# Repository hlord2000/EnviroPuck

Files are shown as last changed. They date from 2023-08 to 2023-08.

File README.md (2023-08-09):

# EnviroPuck 🌍
Introducing the EnviroPuck, a sleek and low-power environment sensing device, utilizing Raytac's MDBT50Q module featuring the nRF52840 chip, and Bosch's BME688 environmental sensor.

<p align="center">
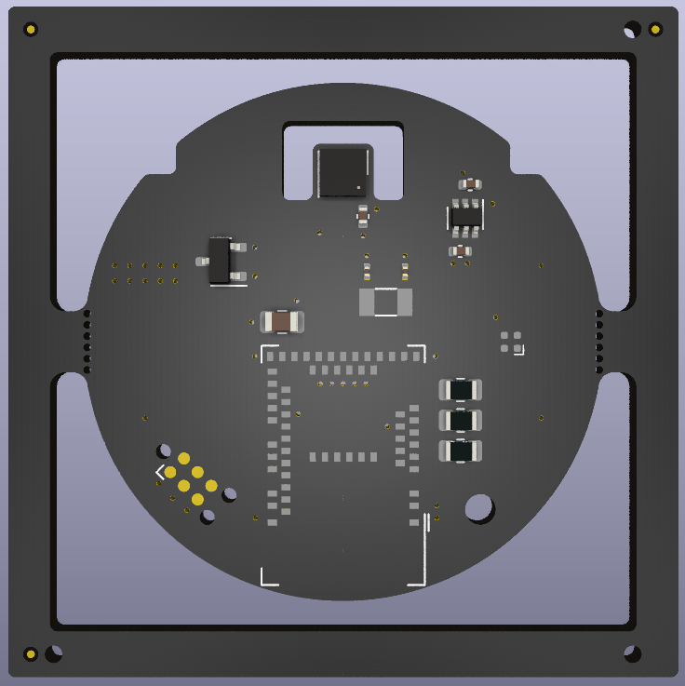
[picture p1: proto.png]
EnviroPuck Prototype
  
</p>

# Features 🎛️
- Raytac MDBT50Q Module with nRF52840: Enables robust wireless connectivity, supporting Matter/Thread protocols 📡
- BME688 Sensor: Accurately monitors temperature, humidity, pressure, and gas conditions 🌡️💧🌀
- Low Power Design: Powered by a single primary cell CR2032, engineered for energy efficiency and long-lasting performance 🔋

# Applications 🏠
- The EnviroPuck is ideal for home automation, indoor climate monitoring, and various IoT applications requiring environmental data.

# Development Status ⚙️
- Hardware: Prototyped
- Firmware: TODO 
- Mechanical Design: TODO

# License 📄
- This project is released under the CERN Open Hardware License V2 - Permissive. More details can be found in the LICENSE file included in the project.

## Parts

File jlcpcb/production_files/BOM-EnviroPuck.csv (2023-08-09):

Comment | Designator | Footprint | LCSC
SC32S-7PF20PPM | Y1 | Crystal_SMD_3215-2Pin_3.2x1.5mm
1k | R5 | R_0805_2012Metric
1k | R4 | R_0805_2012Metric
1k | R3 | R_0805_2012Metric
DMP610DL-7 | Q1 | SOT-23
1u | C6 | C_0402_1005Metric
3.9p | C5 | C_0201_0603Metric
10u | C4 | C_0805_2012Metric
3.9p | C3 | C_0201_0603Metric
100n | C2 | C_0402_1005Metric
1u | C1 | C_0402_1005Metric
LED_RGBA | D1 | LED_Lumex_SML-LX0404SIUPGUSB
MDBT50Q-1MV2 | U3 | Raytac_MDBT50Q
SiP32431DR3 | U1 | SOT-363_SC-70-6
BME680 | U2 | Bosch_LGA-8_3x3mm_P0.8mm_ClockwisePinNumbering
Battery_Cell | BT1 | BatteryHolder_Multicomp_BC-2001_1x2032

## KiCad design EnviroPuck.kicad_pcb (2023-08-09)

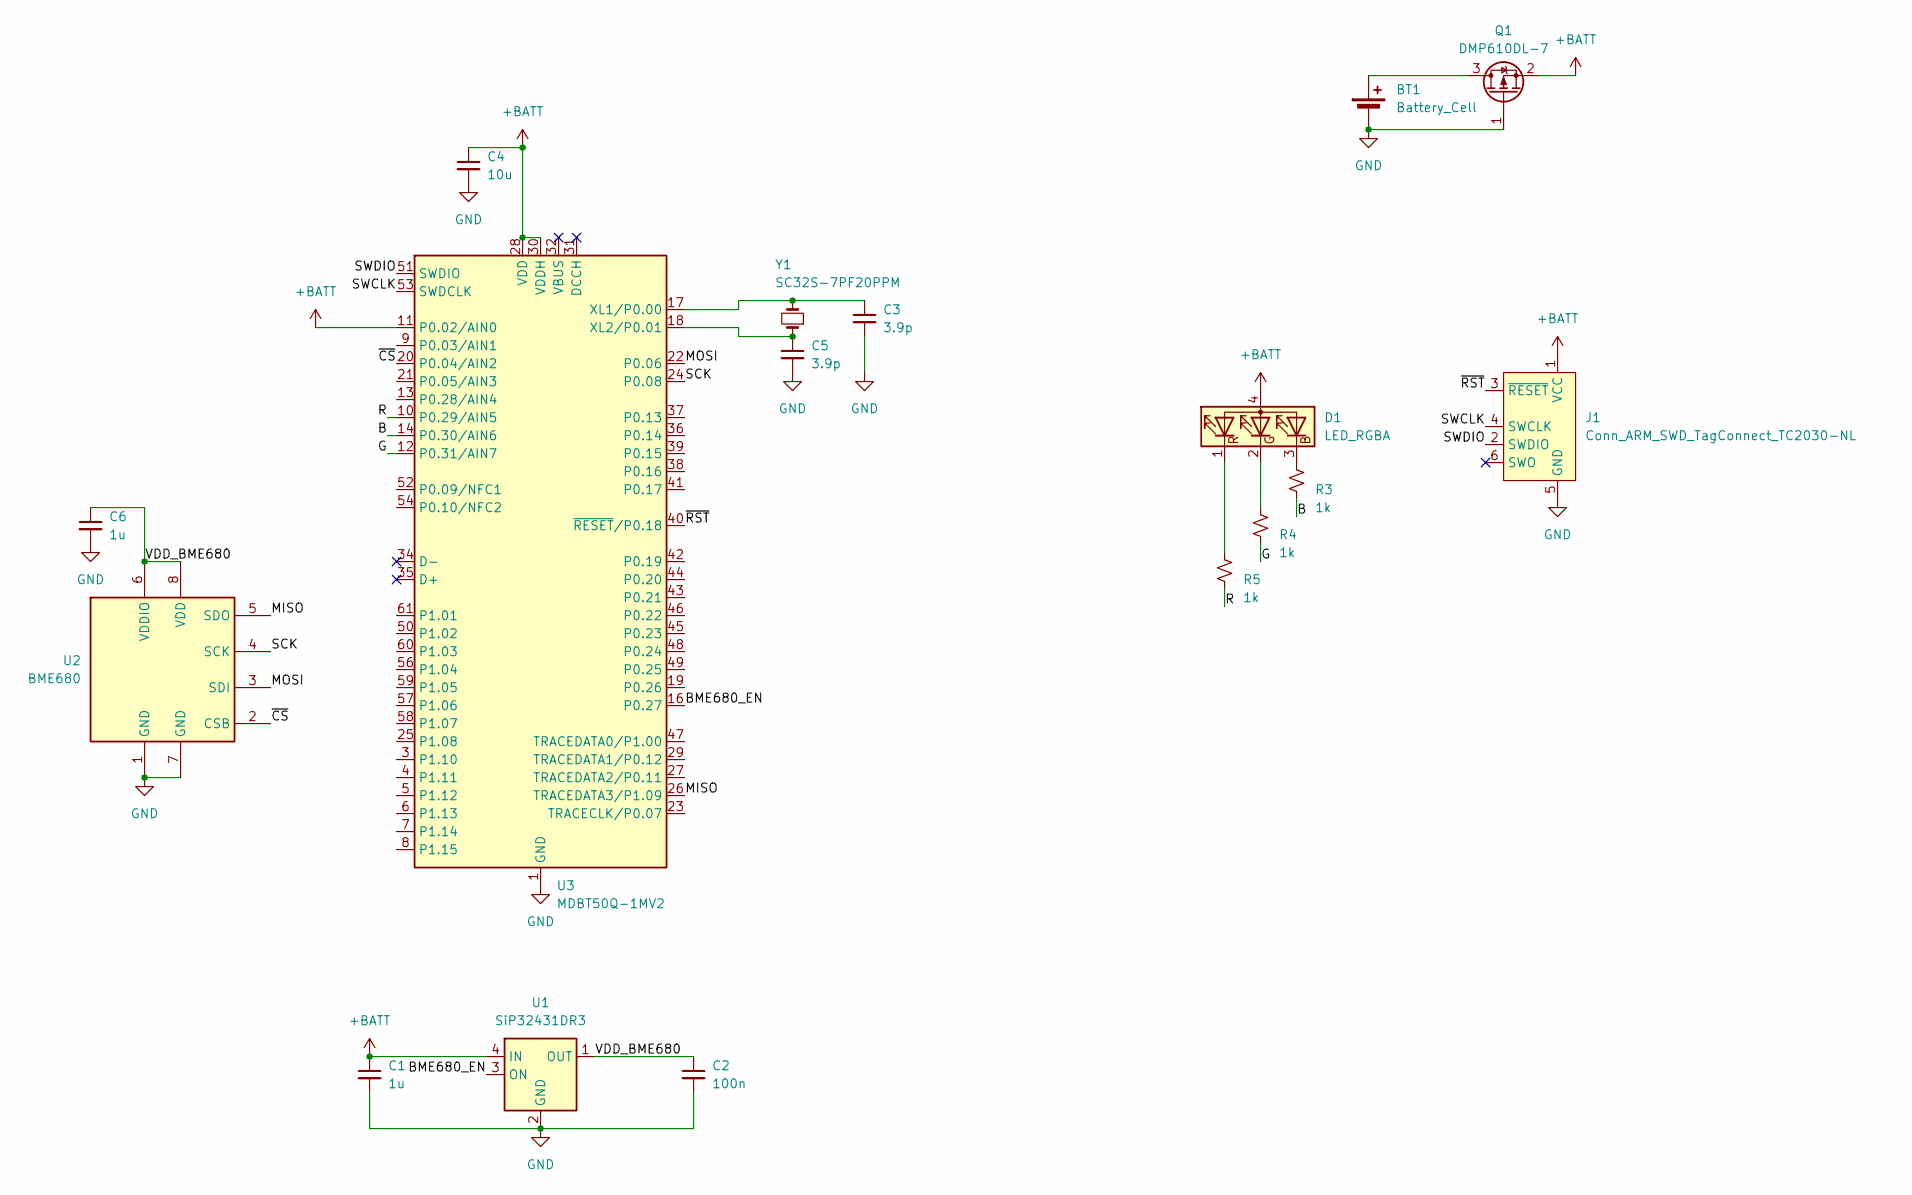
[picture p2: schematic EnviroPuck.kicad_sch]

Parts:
BT1: Battery_Cell; BatteryHolder_Multicomp_BC-2001_1x2032
C1, C6: 1u; C_0402_1005Metric; MPN GRM153C80G105ME15D
C2: 100n; C_0402_1005Metric; MPN CL05B104KA5NNNC
C3, C5: 3.9p; C_0201_0603Metric; MPN GRT0335C1H3R9CA02D
C4: 10u; C_0805_2012Metric; MPN CL21A106KOQNNNE
D1: LED_RGBA; LED_Lumex_SML-LX0404SIUPGUSB
J1: Conn_ARM_SWD_TagConnect_TC2030-NL; Tag-Connect_TC2030-IDC-NL_2x03_P1.27mm_Vertical
Q1: DMP610DL-7; SOT-23; MPN DMP610DL-7
R3, R4, R5: 1k; R_0805_2012Metric; MPN ERJ-6GEYJ102V
U1: SiP32431DR3; SOT-363_SC-70-6
U2: BME680; Bosch_LGA-8_3x3mm_P0.8mm_ClockwisePinNumbering
U3: MDBT50Q-1MV2; Raytac_MDBT50Q
Y1: SC32S-7PF20PPM; Crystal_SMD_3215-2Pin_3.2x1.5mm; MPN SC32S-7PF20PPM

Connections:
+BATT: C1.1, C4.1, D1.4 (A), J1.1 (VCC), Q1.2 (S), U1.4 (IN), U3.11 (P0.02/AIN0), U3.28 (VDD), U3.30 (VDDH)
/B: R3.2, U3.14 (P0.30/AIN6)
/BME680_EN: U1.3 (ON), U3.16 (P0.27)
/G: R4.2, U3.12 (P0.31/AIN7)
/MISO: U2.5 (SDO), U3.26 (TRACEDATA3/P1.09)
/MOSI: U2.3 (SDI), U3.22 (P0.06)
/R: R5.2, U3.10 (P0.29/AIN5)
/SCK: U2.4 (SCK), U3.24 (P0.08)
/SWCLK: J1.4 (SWCLK), U3.53 (SWDCLK)
/SWDIO: J1.2 (SWDIO), U3.51 (SWDIO)
/VDD_BME680: C2.1, C6.1, U1.1 (OUT), U2.6 (VDDIO), U2.8 (VDD)
/~CS: U2.2 (CSB), U3.20 (P0.04/AIN2)
/~RST: J1.3 (~RESET), U3.40 (~RESET/P0.18)
GND: BT1.2 (-), C1.2, C2.2, C3.2, C4.2, C5.2, C6.2, J1.5 (GND), Q1.1 (G), U1.2 (GND), U1.5 (GND), U2.1 (GND), U2.7 (GND), U3.1 (GND), U3.2 (GND), U3.15 (GND), U3.33 (GND), U3.55 (GND)
unnamed: BT1.1 (+), Q1.3 (D)
unnamed: D1.3 (BK), R3.1
unnamed: D1.2 (GK), R4.1
unnamed: D1.1 (RK), R5.1
unnamed: C3.1, U3.17 (XL1/P0.00), Y1.2
unnamed: C5.1, U3.18 (XL2/P0.01), Y1.1

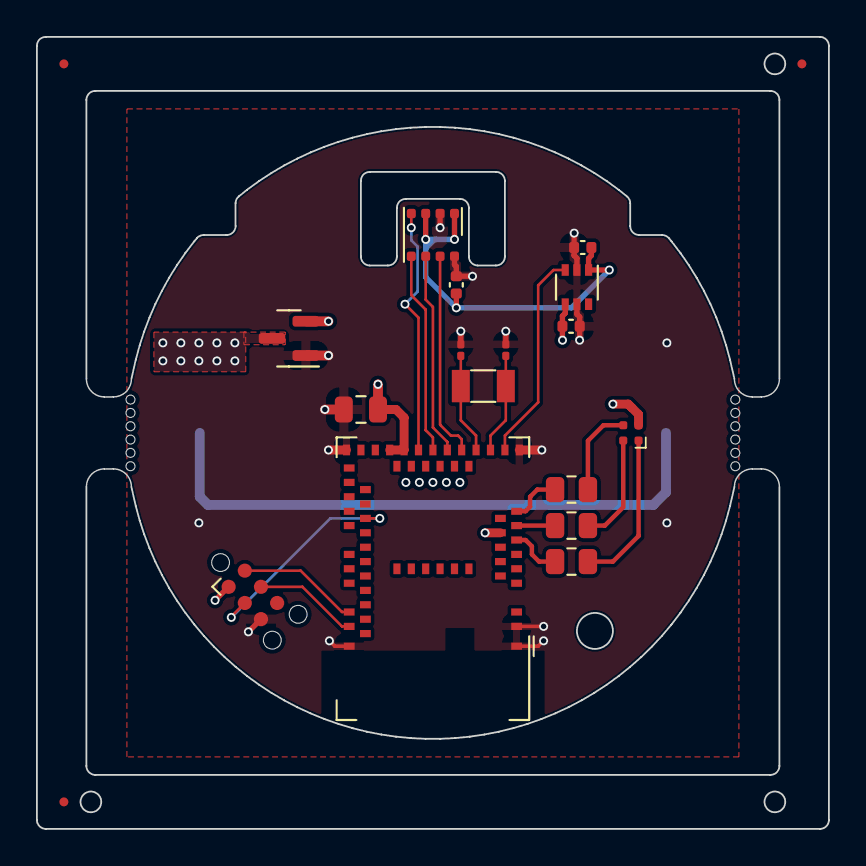
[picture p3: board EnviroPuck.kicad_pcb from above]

Board: 4 copper layers, 44.0 x 44.0 mm, 17 parts (1 on the bottom side), 20 nets.
